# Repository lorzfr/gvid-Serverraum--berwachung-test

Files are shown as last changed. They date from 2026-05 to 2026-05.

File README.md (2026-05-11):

# Serverraumüberwachung mit automatischer Lüftersteuerung

Arduino-Projekt zur Überwachung eines Serverraums: Temperaturmessung, automatische PWM-Lüftersteuerung, Abstandserkennung als Lüfter-Stopp und Statusanzeige auf einem 16x2-I2C-LCD.

Es gibt zwei Sketch-Varianten:

| Sketch | Sensoren | Zusatznutzen |
|---|---|---|
| `serverroom_fan_control-TMP36.ino` | TMP36 + HC-SR04 | schnelle analoge Temperaturmessung |
| `serverroom_fan_control_dht11.ino` | DHT11 + HC-SR04 | Temperatur plus Luftfeuchtigkeit |

## Funktionen

- Temperaturabhängige Lüfterfreigabe mit Hysterese:
  - Einschalten ab `30.0 °C`
  - Ausschalten unter `28.0 °C`
- PWM-Regelung zwischen `FAN_PWM_MIN = 100` und `FAN_PWM_MAX = 255`
- Glättung der Temperaturwerte per gleitendem Mittelwert
  - TMP36: 10 Messwerte
  - DHT11: 5 Messwerte
- Personenerkennung über HC-SR04:
  - unter `50 cm` wird der Lüfter abgeschaltet
- Failsafe bei Sensorfehlern:
  - TMP36-Version: HC-SR04-Fehler setzt den Lüfter auf 100 %
  - DHT11-Version: DHT11- oder HC-SR04-Fehler setzt den Lüfter auf 100 %
- Serielle Debug-Ausgabe mit `9600 Baud`

## Hardware

- Arduino Mega 2560
- 5-V-Lüfter mit PWM-/Steuereingang oder geeigneter Treiberstufe
- TMP36 **oder** DHT11
- HC-SR04 Ultraschallsensor
- 16x2-I2C-LCD, Standardadresse im Code: `0x27`
- Jumper-Kabel, ggf. Breadboard

> Wichtig: Einen Lüfter nicht direkt über einen Arduino-I/O-Pin mit Strom versorgen. Der Pin `D9` ist in den Sketches als PWM-/Steuersignal vorgesehen. Die Lüfterversorgung muss zur Stromaufnahme des Lüfters passen; bei einem einfachen DC-Lüfter wird eine Treiberstufe, z. B. Transistor oder MOSFET mit Freilaufdiode, benötigt.

## Pinbelegung

### Gemeinsame Anschlüsse

| Komponente | Anschluss | Arduino Mega 2560 |
|---|---:|---:|
| HC-SR04 | TRIG | D3 |
| HC-SR04 | ECHO | D4 |
| HC-SR04 | VCC | 5V |
| HC-SR04 | GND | GND |
| Lüfter | PWM/Steuersignal | D9 |
| I2C-LCD | SDA | D20/SDA |
| I2C-LCD | SCL | D21/SCL |
| I2C-LCD | VCC | 5V |
| I2C-LCD | GND | GND |

### TMP36-Version

| Komponente | Anschluss | Arduino Mega 2560 |
|---|---:|---:|
| TMP36 | Signal | A0 |
| TMP36 | VCC | 5V |
| TMP36 | GND | GND |

### DHT11-Version

| Komponente | Anschluss | Arduino Mega 2560 |
|---|---:|---:|
| DHT11 | DAT | D2 |
| DHT11 | VCC | 5V |
| DHT11 | GND | GND |

> Hinweis: Bei einem nackten DHT11-Sensor wird normalerweise ein Pull-up-Widerstand zwischen DAT und VCC benötigt. Viele DHT11-Module haben diesen Widerstand bereits auf der Platine.

## Benötigte Arduino-Libraries

Über den Arduino Library Manager installieren:

- Für beide Sketches: `LiquidCrystal_I2C` von Frank de Brabander
- Zusätzlich für `serverroom_fan_control_dht11.ino`:
  - `DHT sensor library` von Adafruit
  - `Adafruit Unified Sensor` von Adafruit

## Schnellstart

1. Hardware nach Pinbelegung anschließen.
2. Gewünschte Sketch-Variante in der Arduino IDE öffnen:
   - `serverroom_fan_control-TMP36.ino`
   - oder `serverroom_fan_control_dht11.ino`
3. Benötigte Libraries installieren.
4. Board `Arduino Mega or Mega 2560` und den richtigen Port auswählen.
5. Sketch hochladen.
6. Seriellen Monitor auf `9600 Baud` öffnen oder Werte auf dem LCD prüfen.
7. Wenn das LCD leer bleibt, im Sketch `LCD_I2C_ADDR` von `0x27` auf `0x3F` ändern und erneut hochladen.

## Funktionstest

- Sensor erwärmen: Lüfterfreigabe startet ab etwa `30 °C`.
- Sensor abkühlen lassen: Lüfterfreigabe endet erst unter `28 °C`.
- Hand vor den HC-SR04 halten: Bei weniger als `50 cm` wird `PERSON DETECTED!` angezeigt und der Lüfter stoppt.
- HC-SR04-Echo-Verbindung trennen oder Timeout simulieren: Failsafe setzt den Lüfter auf 100 %.
- Nur DHT11-Version: DHT11 trennen oder Fehlmessung auslösen; das Display zeigt `ERR`/`SENSOR ERROR!`, der Lüfter läuft mit 100 %.

## Dateien im Repository

```text
.
├── README.md
├── LICENSE
├── doc/
│   ├── dokumenation.md
│   └── Dokumentation-als-PDF.txt
├── serverroom_fan_control-TMP36.ino
├── serverroom_fan_control_dht11.ino
├── serverraumüberwachung.fzz
├── serverraumüberwachung_bb.png
├── serverraumüberwachung_PAP.png
├── IMG_2060.jpeg
├── IMG_2066.jpeg
└── IMG_2067.jpeg
```

## Dokumentation und Medien

- Ausführlichere Projektdokumentation: `doc/dokumenation.md`
- Hinweis zur PDF-Abgabe: `doc/Dokumentation-als-PDF.txt`
- Fritzing-Projekt: `serverraumüberwachung.fzz`
- Exportierter Breadboard-Aufbau: `serverraumüberwachung_bb.png`
- Programmablaufplan: `serverraumüberwachung_PAP.png`
- Fotos des Aufbaus: `IMG_2060.jpeg`, `IMG_2066.jpeg`, `IMG_2067.jpeg`

## Bilder

### Fritzing-Aufbau

Fritzing-Export des Breadboard-Aufbaus

### Programmablaufplan

Programmablaufplan

### Realer Aufbau

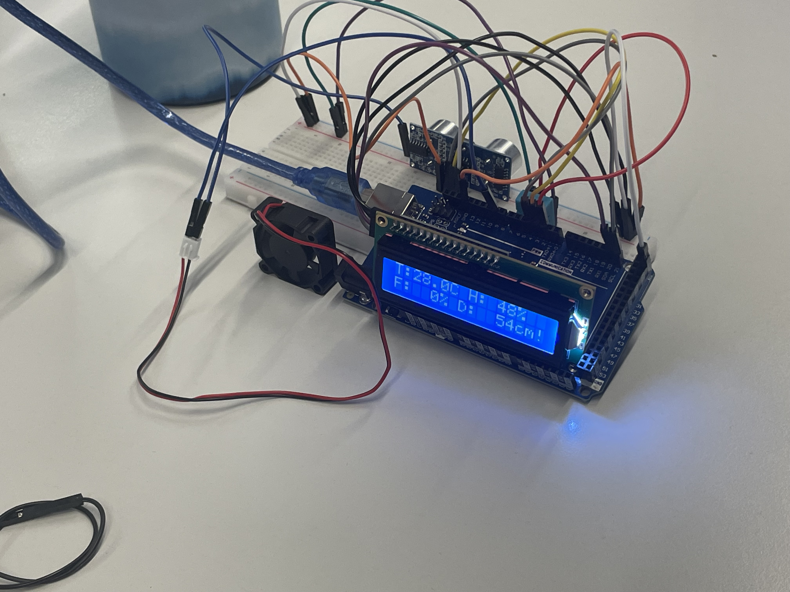
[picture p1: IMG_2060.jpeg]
Aufbau 1

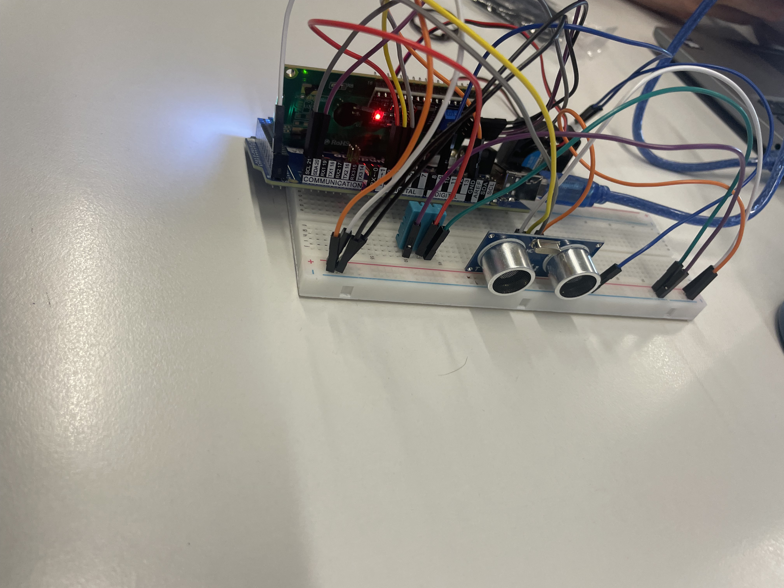
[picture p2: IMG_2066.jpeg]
Aufbau 2

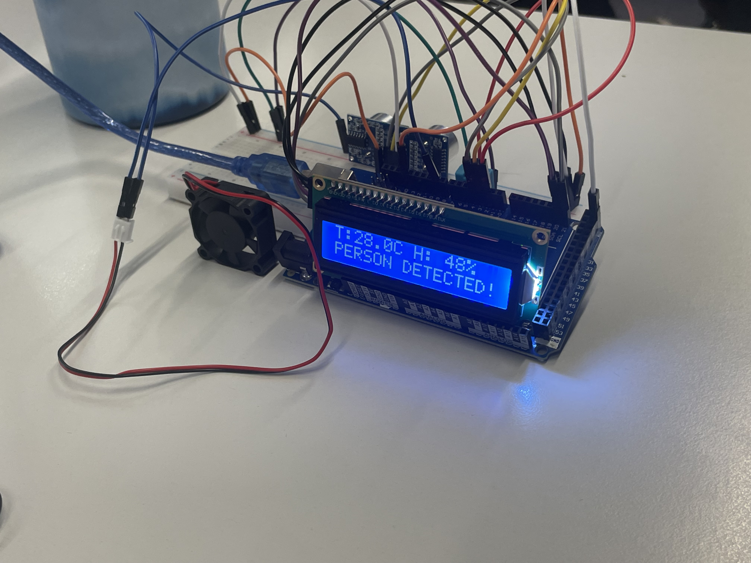
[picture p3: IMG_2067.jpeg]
Aufbau 3


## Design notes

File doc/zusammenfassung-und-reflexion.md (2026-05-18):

# 5. Zusammenfassung und Reflexion

Dieses Kapitel fasst den aktuellen Stand der Serverraumüberwachung zusammen, bewertet die erreichten Ergebnisse und beschreibt sinnvolle Erweiterungen für eine mögliche Version 2.0. Im Mittelpunkt stehen die temperaturabhängige Lüftersteuerung, die Sicherheitsabschaltung über Abstandserkennung, die Anzeige der Betriebswerte und der Umgang mit Sensorfehlern.

## 5.1 Ergebnisse: Was funktioniert gut?

Das Projekt erfüllt die wichtigsten Anforderungen an eine einfache Serverraumüberwachung. Die Temperatur wird regelmäßig erfasst und als Grundlage für die automatische Lüftersteuerung genutzt. Dadurch muss der Lüfter nicht dauerhaft mit voller Leistung laufen, sondern wird abhängig von der gemessenen Temperatur geregelt. Das spart Energie, reduziert Geräusche und sorgt trotzdem dafür, dass bei steigender Temperatur aktiv gekühlt wird.

Besonders gut funktioniert die Hysterese zwischen Einschalt- und Ausschaltpunkt. Der Lüfter startet erst ab einer definierten Temperatur und schaltet erst wieder ab, wenn die Temperatur ausreichend gefallen ist. Dadurch wird verhindert, dass der Lüfter bei kleinen Messschwankungen ständig an- und ausgeht. Diese Logik macht das System stabiler und praxistauglicher.

Auch die PWM-Regelung ist ein wichtiger Vorteil. Der Lüfter wird nicht nur ein- oder ausgeschaltet, sondern kann in seiner Leistung angepasst werden. Mit einem Mindest-PWM-Wert wird sichergestellt, dass der Lüfter zuverlässig anlaufen kann, sobald Kühlung benötigt wird. Bei höheren Temperaturen wird die Lüfterleistung weiter erhöht.

Die Glättung der Temperaturwerte verbessert die Anzeige und die Regelung. Einzelne Ausreißer oder kleine Messungenauigkeiten wirken sich dadurch weniger stark auf das Verhalten des Lüfters aus. Das ist vor allem bei analogen Sensoren wie dem TMP36 hilfreich, aber auch bei digitalen Messwerten sinnvoll.

Die Personenerkennung über den HC-SR04 ist ebenfalls ein sinnvoller Sicherheitsbestandteil. Wenn eine Person oder ein Gegenstand zu nah am Lüfter erkannt wird, stoppt der Lüfter automatisch. Damit wird das Projekt nicht nur als Temperaturregelung, sondern auch als sicherheitsbewusstes Überwachungssystem umgesetzt.

Ein weiterer positiver Punkt ist die Fehlerbehandlung. Bei ungültigen Sensorwerten oder Problemen mit der Abstandsmessung wird ein Failsafe aktiviert. Der Lüfter läuft dann mit voller Leistung, damit im Zweifel eher gekühlt wird, anstatt eine mögliche Überhitzung zu riskieren. Besonders in einem Serverraum ist dieses Verhalten sinnvoll, weil ein Ausfall der Kühlung größere Schäden verursachen könnte.

Die Ausgabe auf dem LCD und über den seriellen Monitor erleichtert die Kontrolle des Systems. Temperatur, Lüfterleistung, Abstand und Statusmeldungen können direkt beobachtet werden. Dadurch lassen sich Tests einfacher durchführen und Fehler schneller eingrenzen.

Zusammengefasst funktionieren vor allem diese Punkte gut:

- automatische Temperaturüberwachung,
- temperaturabhängige Lüftersteuerung mit PWM,
- stabile Hysterese gegen häufiges Ein- und Ausschalten,
- geglättete Messwerte für ruhigere Regelung,
- Personenerkennung als Sicherheitsfunktion,
- Failsafe bei Sensorfehlern,
- verständliche Anzeige von Messwerten und Statusinformationen.

## 5.2 Probleme: Wo gibt es noch offene Baustellen?

Trotz der funktionierenden Grundfunktionen gibt es noch einige offene Punkte. Die Genauigkeit der Temperaturmessung hängt stark vom verwendeten Sensor und von der Positionierung im Aufbau ab. Ein TMP36 kann durch analoge Störungen beeinflusst werden, während ein DHT11 vergleichsweise langsam und ungenau ist. Für eine echte Serverraumüberwachung wäre eine genauere und professionellere Sensorik sinnvoll.

Auch die Luftfeuchtigkeit wird nur in der DHT11-Version erfasst. In einem Serverraum ist Luftfeuchtigkeit jedoch ebenfalls relevant, weil zu hohe oder zu niedrige Werte langfristig problematisch für elektronische Geräte sein können. In der aktuellen Umsetzung wird die Luftfeuchtigkeit zwar angezeigt, aber noch nicht aktiv für Warnungen oder Regelentscheidungen genutzt.

Die Abstandsmessung mit dem HC-SR04 kann in bestimmten Situationen unzuverlässig sein. Schräg stehende Flächen, weiche Materialien oder ungünstige Reflexionen können Messfehler verursachen. Außerdem ist die Personenerkennung sehr einfach umgesetzt: Alles unterhalb des Grenzwerts wird als Person oder Hindernis interpretiert. Eine genauere Unterscheidung findet noch nicht statt.

Eine weitere Baustelle ist die Hardware-Auslegung des Lüfters. Der Arduino-Pin darf den Lüfter nicht direkt mit Strom versorgen. Für einen dauerhaft zuverlässigen Betrieb ist eine passende Treiberstufe mit Transistor oder MOSFET sowie eine sichere Spannungsversorgung notwendig. Dieser Punkt ist wichtig, wenn aus dem Versuchsaufbau ein dauerhaft nutzbares System werden soll.

Die Anzeige ist nützlich, aber durch das 16x2-LCD begrenzt. Es können nur wenige Informationen gleichzeitig dargestellt werden. Für ausführlichere Diagnosen, Verlaufsdaten oder mehrere Sensorwerte wäre eine umfangreichere Benutzeroberfläche besser geeignet.

Außerdem speichert das System aktuell keine Messwerte. Nach einem Neustart oder nach einem Fehler ist nicht nachvollziehbar, wie sich Temperatur, Abstand oder Fehlerzustände vorher entwickelt haben. Für eine echte Überwachung wäre Logging sehr hilfreich.

Offene Baustellen sind daher vor allem:

- begrenzte Genauigkeit der verwendeten Sensoren,
- keine Kalibrierung der Temperaturmessung,
- Luftfeuchtigkeit wird noch nicht für Alarme genutzt,
- mögliche Fehlmessungen beim Ultraschallsensor,
- einfache Hindernis-/Personenerkennung ohne Plausibilitätsprüfung,
- notwendige robuste Lüfter-Treiberstufe für den Dauerbetrieb,
- begrenzte Informationsdarstellung auf dem LCD,
- keine Speicherung oder Auswertung von Messdaten.

## 5.3 Ausblick: Welche Funktionen könnten in einer Version 2.0 ergänzt werden?

In einer Version 2.0 könnte das Projekt deutlich erweitert und näher an eine professionelle Serverraumüberwachung gebracht werden. Eine wichtige Verbesserung wäre der Einsatz genauerer Sensoren, zum Beispiel eines DHT22, BME280 oder eines anderen präziseren Temperatur- und Feuchtigkeitssensors. Damit könnten Temperatur und Luftfeuchtigkeit zuverlässiger gemessen und besser ausgewertet werden.

Zusätzlich wäre ein Datenlogging sinnvoll. Messwerte könnten auf einer SD-Karte gespeichert oder über eine Netzwerkverbindung an einen Server gesendet werden. Dadurch ließen sich Temperaturverläufe analysieren, Fehlerereignisse dokumentieren und Langzeittests besser auswerten.

Eine Alarmfunktion wäre ebenfalls ein großer Mehrwert. Bei zu hoher Temperatur, kritischer Luftfeuchtigkeit oder Sensorfehlern könnte das System über eine LED, einen Buzzer, eine E-Mail, eine Push-Nachricht oder eine Web-Oberfläche warnen. Dadurch müsste nicht dauerhaft jemand das LCD beobachten.

Für eine moderne Umsetzung könnte ein ESP32 oder ein ähnlicher Mikrocontroller genutzt werden. Damit wäre eine WLAN-Anbindung möglich. Das System könnte dann ein Web-Dashboard bereitstellen, Messwerte live anzeigen und Einstellungen wie Grenzwerte oder Betriebsmodi direkt über den Browser anpassbar machen.

Auch mehrere Sensoren wären sinnvoll. In einem Serverraum gibt es oft Temperaturunterschiede zwischen verschiedenen Bereichen. Mit mehreren Messpunkten könnte das System Hotspots erkennen und die Lüftersteuerung genauer anpassen.

Für den praktischen Betrieb wären außerdem verschiedene Betriebsmodi hilfreich. Neben dem Automatikmodus könnte es einen manuellen Modus, einen Wartungsmodus und einen Notfallmodus geben. So könnte der Lüfter bei Tests gezielt gesteuert oder bei Wartungsarbeiten sicher deaktiviert werden.

Mögliche Erweiterungen für Version 2.0 sind:

- präzisere Sensoren wie DHT22 oder BME280,
- Kalibrierfunktion für Temperatur- und Feuchtigkeitswerte,
- Speicherung von Messwerten auf SD-Karte,
- Netzwerkübertragung der Daten,
- Web-Dashboard für Live-Anzeige und Konfiguration,
- Alarmierung per LED, Buzzer, E-Mail oder Push-Nachricht,
- mehrere Temperaturmesspunkte im Raum,
- Grenzwerte für Luftfeuchtigkeit,
- bessere Plausibilitätsprüfung der Abstandsmessung,
- einstellbare Betriebsmodi wie Auto, Manuell, Wartung und Notfall,
- stabilere Hardware mit geeigneter Lüfter-Treiberstufe und Gehäuse.

Insgesamt bietet die aktuelle Version eine funktionierende Grundlage. Die wichtigsten Kernfunktionen sind vorhanden, aber Version 2.0 könnte das System genauer, komfortabler, besser vernetzbar und zuverlässiger für den Dauerbetrieb machen.

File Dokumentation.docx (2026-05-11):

Serverraum Überwachungssystem

- Was wurde entwickelt und warum?

Wir haben ein Überwachungssystem entwickelt um unseren Serverraum rund um die Uhr Sicher und ihm eine geeignete Umgebung zu gewährleisten. Darunter zählen ein Temperatur Messer, einen Abstandsmesser und einen Feuchtigkeitsmesser.

- Ziele und Anforderungen

Unser Überwachungssystem soll dafür sorgen, dass der Serverraum nie zu warm oder zu feucht wird. Außerdem sollen bei Arbeiten im Serverraum der Lüfter für die Kühlung ausgeschaltet werden, um das Unfallrisiko zu verringern.

- Verwendete Technologien
- Hardware: Arduino, Bread-Board, Ultraschallsensor, LCD-Bildschirm, 12V Lüfter, Kabel, USB-A auf USB-B Kabel
- Software: fritzing
- Teammitglieder
- Um die Software hat Lars sich gekümmert und das Skript geschrieben
- Hardwareinstallation hat Luca übernommen
- Dokumentation haben beide zusammen bearbeitet

18.05.2026 Herr Meier

Inhaltsverzeichnis

1. Technische Dokumentation
  - Schaltplan
  - Hardwareliste
2. Code-Dokumentation
  - Logik-Visualisierung
  - Quellcode
3. Testphase und Fehlerbehebung
  - Fehlerprotokoll
  - Testreihen
4. Benutzeranleitung
  - Wie wird das System gestartet?
  - Welche Bedienelemente (Taster, Potentiometer) gibt es?
  - Wie interpretiert man die Ausgaben auf dem Display
5. Zusammenfassung und Reflektion
  - Ergebnisse: Was funktioniert gut?
  - Probleme: Wo gibt es noch offene Baustellen?
  - Ausblick: Welche Funktionen könnten in einer Version 2.0 ergänzt werden

Technische Dokumentation

- Der Schaltplan

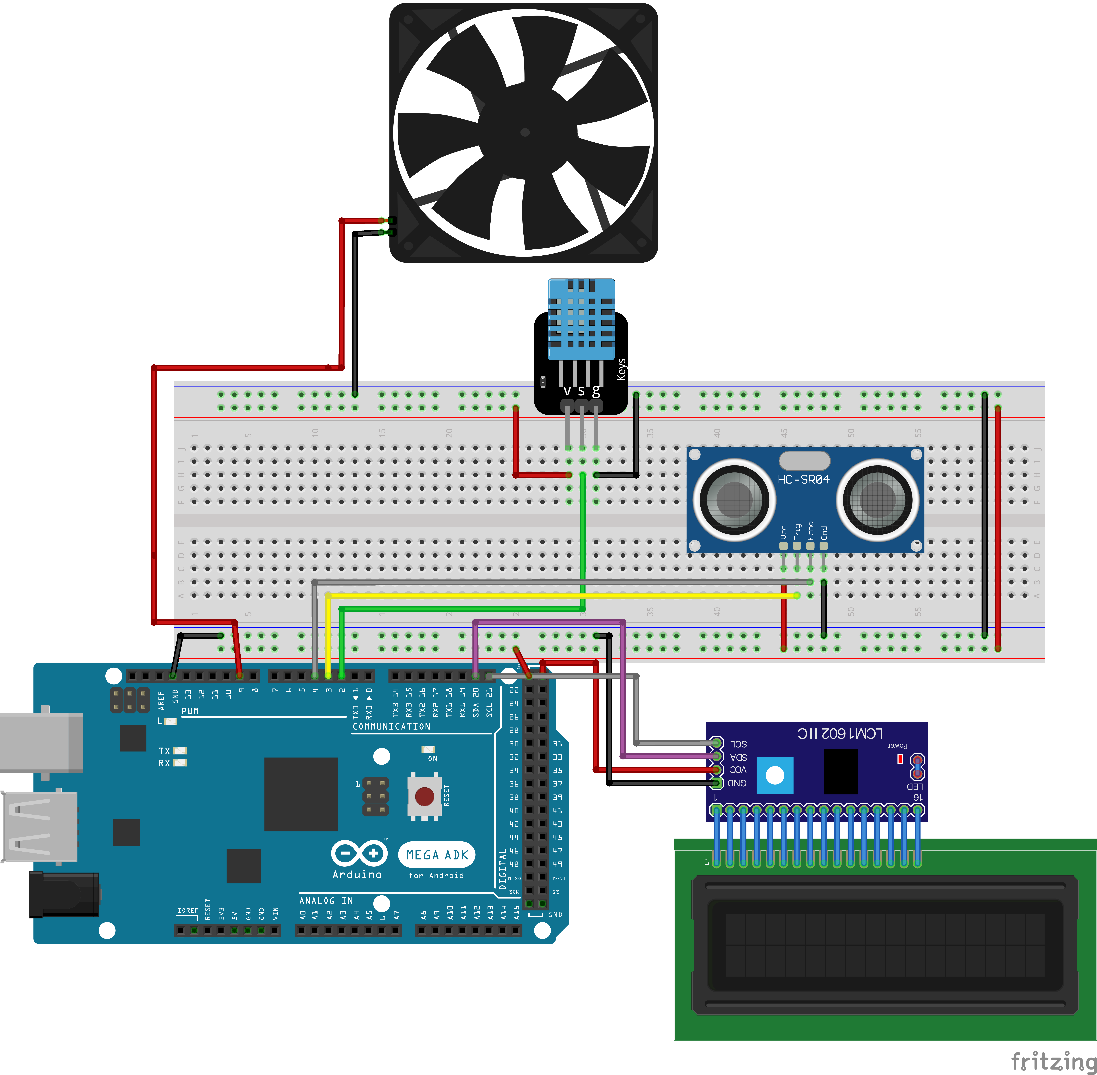
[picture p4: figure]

Hardwareliste

1x Arduino Mega 2560

1x TMP36 oder 1x DHT11

1x HC-SR04 Ultraschallsensor

1x I2C LCD 16x2

1x 5V PWM-Lüfter

Verbindungskabel, ggf. Breadboard

Code-Dokumentation

- Logik-Visualisierung

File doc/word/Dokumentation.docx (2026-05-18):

Serverraum Überwachungssystem

- Was wurde entwickelt und warum?

Wir haben ein Überwachungssystem entwickelt um unseren Serverraum rund um die Uhr Sicher und ihm eine geeignete Umgebung zu gewährleisten. Darunter zählen ein Temperatur Messer, einen Abstandsmesser und einen Feuchtigkeitsmesser.

- Ziele und Anforderungen

Unser Überwachungssystem soll dafür sorgen, dass der Serverraum nie zu warm oder zu feucht wird. Außerdem sollen bei Arbeiten im Serverraum der Lüfter für die Kühlung ausgeschaltet werden, um das Unfallrisiko zu verringern.

- Verwendete Technologien
- Hardware: Arduino, Bread-Board, Ultraschallsensor, LCD-Bildschirm, 12V Lüfter, Kabel, USB-A auf USB-B Kabel
- Software: fritzing
- Teammitglieder
- Um die Software hat Lars sich gekümmert und das Skript geschrieben
- Hardwareinstallation hat Luca übernommen
- Dokumentation haben beide zusammen bearbeitet

Inhaltsverzeichnis

1. Technische Dokumentation
  1.1 Schaltplan
  1.2 Hardwareliste
2. Code-Dokumentation
  2.1 Logik-Visualisierung
  2.2 Quellcode
3. Testphase und Fehlerbehebung
  3.1 Fehlerprotokoll
  3.2 Testreihen
4. Benutzeranleitung
  4.1 Wie wird das System gestartet?
  4.2 Welche Bedienelemente (Taster, Potentiometer) gibt es?
  4.3 Wie interpretiert man die Ausgaben auf dem Display
5. Zusammenfassung und Reflektion
  5.1 Ergebnisse: Was funktioniert gut?
  5.2 Probleme: Wo gibt es noch offene Baustellen?
  5.3 Ausblick: Welche Funktionen könnten in einer Version 2.0 ergänzt werden
6. Anhang
  6.1 Anhang zum Quellcode

1. Technische Dokumentation

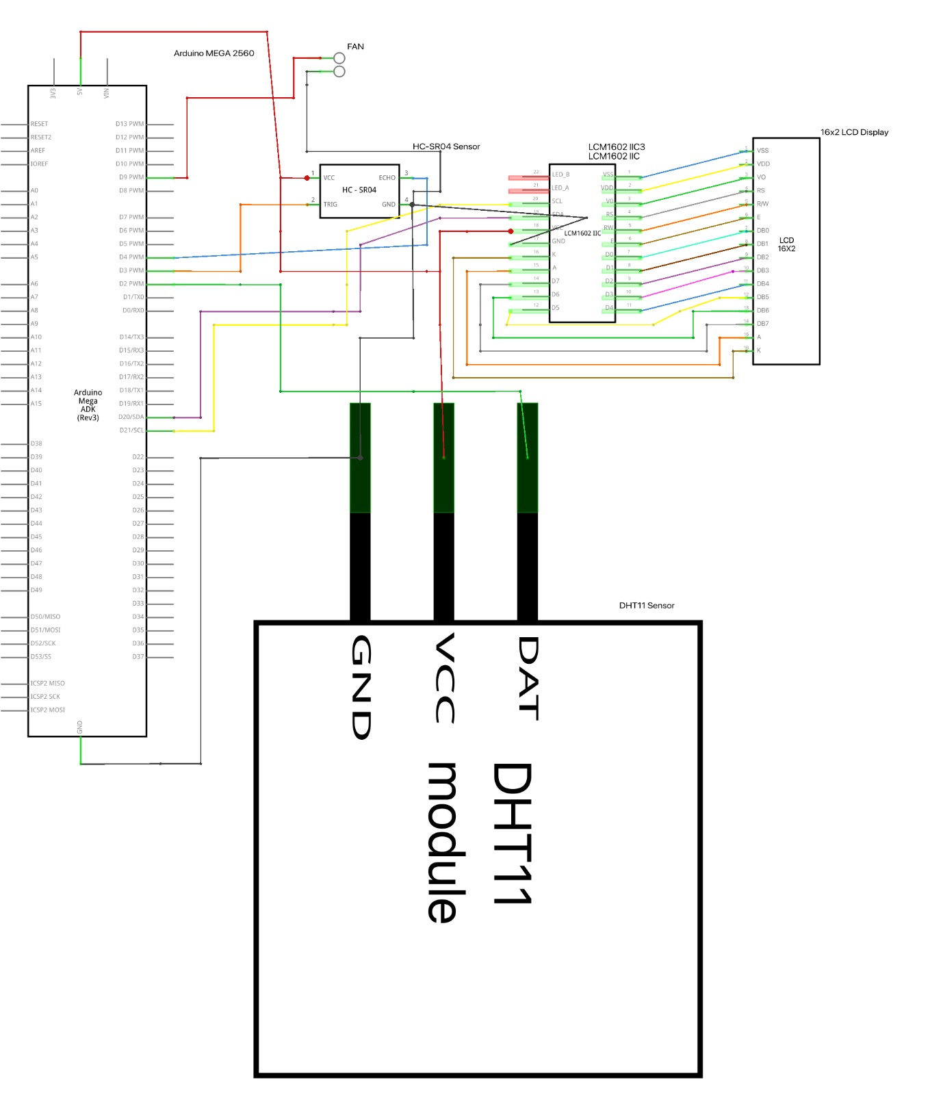
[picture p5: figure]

1.1 Der Schaltplan

1.2 Hardwareliste

1x Arduino Mega 2560

1x TMP36 oder 1x DHT11

1x HC-SR04 Ultraschallsensor

1x I2C LCD 16x2

1x 5V PWM-Lüfter

Verbindungskabel, ggf. Breadboard

2. Code-Dokumentation

2.1 Logik-Visualisierung

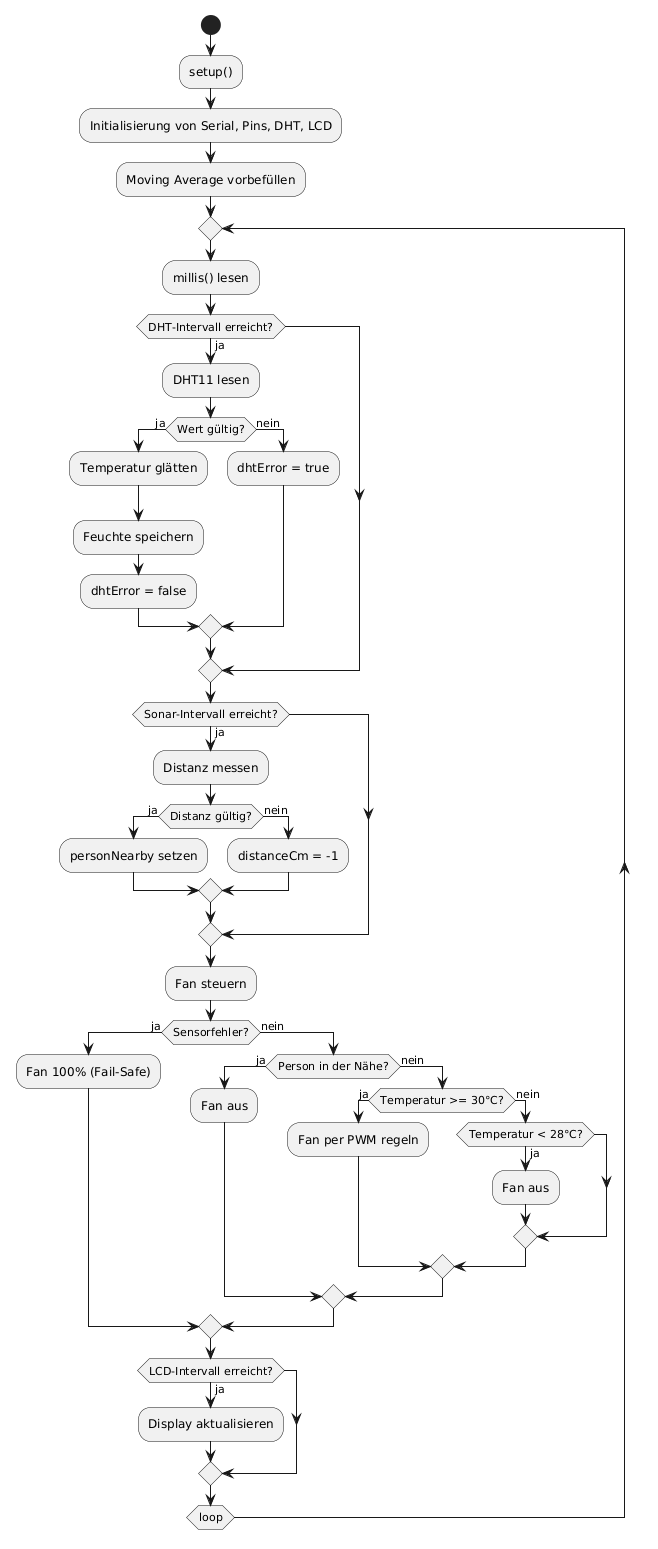
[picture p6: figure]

2. Code-Dokumentation

2.2 Der Quellcode

- Temperaturgrenzen:
  - TEMP_FAN_ON = 30.0°C
  - TEMP_FAN_OFF = 28.0°C (Hysterese)
- PWM-Mapping: linear von TEMP_MIN_MAP = 20.0°C bis TEMP_MAX_MAP = 40.0°C auf den Bereich FAN_PWM_MIN bis 255.
- Personenschutz: Wenn Distanz < PERSON_DIST_CM (50 cm), wird der Lüfter abgeschaltet.
- Failsafe: Bei Sensorausfall läuft Lüfter mit 100%, um Überhitzung zu vermeiden.
- DHT11 darf nur langsam gelesen werden, deshalb INTERVAL_DHT = 2000 ms.
- Gleitender Mittelwert mit 5 Samples (passend zur langsameren DHT11-Rate).
- Zusätzlicher Fehlerzustand dhtError; Failsafe bei DHT- oder Sonarfehler.

Wichtige Funktionen

- smoothedTemperature() – Mittelwertbildung.
- updateFan() – Failsafe bei dhtError || distanceCm == -1.
- updateDisplay() – zeigt Temperatur, Feuchte, Lüfter und Distanz; im Fehlerfall „ERR“.

3. Testphase und Fehlerbehebung

3.1 Fehlerprotokoll

1. LCD bleibt leer
  - Ursache: falsche I2C-Adresse.
  - Lösung: 0x27 auf 0x3F ändern.
2. DHT11 liefert NaN
  - Ursache: zu schnelle Abfrage / Leitungsproblem.
  - Lösung: 2-Sekunden-Intervall einhalten, Verkabelung prüfen.
3. HC-SR04 keine Werte
  - Ursache: Echo-Timeout oder Reichweite überschritten.
  - Lösung: Timeout/Verkabelung prüfen; System setzt automatisch Failsafe.
4. Lüfter startet nicht zuverlässig
  - Ursache: PWM-Startwert zu niedrig.
  - Lösung: FAN_PWM_MIN erhöhen.

3.2 Testreihen

- Schwellwerttest: Sensor erwärmen (z. B. Föhn), prüfen, ob Lüfter ab ~30°C startet.
- Hysterese-Test: Temperatur langsam senken, prüfen, ob Lüfter erst unter 28°C ausgeht.
- Personenschutz-Test: Hand vor HC-SR04 (<50 cm), Lüfter muss stoppen.
- Failsafe-Test Sonar: Echo-Leitung lösen/simulieren, Lüfter muss 100% laufen.
- Failsafe-Test DHT11: DHT11 trennen, Lüfter muss 100% laufen.
- Langzeittest: 30–60 Minuten Betrieb, stabile Anzeige und keine Hänger.
  4. Benutzeranleitung

4.1 Wie wird das System gestartet?

1. Hardware gemäß Schaltplan anschließen.
2. Passenden Sketch hochladen:
  - serverroom_fan_control-TMP36.ino oder
  - serverroom_fan_control_dht11.ino
3. Arduino mit Strom versorgen.
4. Nach Initialisierung erscheinen Messwerte auf dem LCD.

4.2 Welche Bedienelemente (Taster, Potenziometer) gibt es?

- Es gibt keine aktiven Bedienelemente; das System arbeitet automatisch.
- Optional können Grenzwerte im Code angepasst werden:
  - TEMP_FAN_ON, TEMP_FAN_OFF
  - PERSON_DIST_CM
  - FAN_PWM_MIN

4.3 Wie interpretiert man die Ausgabe auf dem Display?

- Zeile 1: Temperatur (und bei DHT11 auch Luftfeuchte)
- Zeile 2: Lüfterleistung in % und Distanz
- Sonderanzeigen:
  - PERSON DETECTED! → Lüfter aus
  - SENSOR ERROR! bzw. ERR-Werte → Failsafe aktiv
5. Zusammenfassung und Reflektion

5.1 Ergebnisse: Was funktioniert gut?

- Das System erfüllt die Kernfunktion: temperaturabhängige Lüftersteuerung.
- Sicherheits- und Failsafe-Mechanismen erhöhen die Betriebssicherheit.
- Die modulare Struktur (Lesen, Regeln, Anzeigen) verbessert Wartbarkeit und Erweiterbarkeit.

5.2 Probleme: Wo gibt es noch offene Baustellen?

- Ohne Kalibrierung können absolute Temperaturwerte je nach Sensor leicht abweichen.
- DHT11 ist relativ ungenau und langsam.
- HC-SR04 kann in engen/geometrisch ungünstigen Umgebungen Fehlmessungen erzeugen.

5.3 Ausblick: Welche Funktionen könnten in einer Version 2.0 ergänzt werden?

- Austausch DHT11 gegen DHT22 oder BME280 für genauere Messungen.
- Logging auf SD-Karte (Temperaturverlauf, Fehlerereignisse).
- Alarmfunktion (Buzzer/LED/Nachricht) bei Grenzwertüberschreitung.
- Web-Dashboard (z. B. per ESP32) für Fernüberwachung.
- Manuelle Betriebsmodi (Auto/Manuell/Service).
6. Anhang

6.1 Der Verwendete Quellcode: gvid-serverraum-ueberwachung/serverroom_fan_control_dht11.ino at main · lorzfr/gvid-serverraum-ueberwachung (https://github.com/lorzfr/gvid-serverraum-ueberwachung/blob/main/serverroom_fan_control_dht11.ino)

Lars, Luca GviD Herr Meier

18.05.2026, Löhne Dokumentation.docx

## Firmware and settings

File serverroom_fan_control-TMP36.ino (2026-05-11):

// =============================================================
//  Server Room Fan Controller – Variante mit TMP36
//
//  Ziel des Sketches:
//    * Temperatur analog über einen TMP36 messen.
//    * Per Ultraschallsensor erkennen, ob eine Person nahe am Lüfter steht.
//    * Den 5-V-Lüfter temperaturabhängig per PWM regeln.
//    * Messwerte und Status auf einem 16x2-I2C-LCD sowie seriell ausgeben.
//
//  Board  : Arduino Mega 2560
//  Sensor : TMP36  (analoger Temperatursensor)
//  Sensor : HC-SR04 (digitale Abstandsmessung)
//  Display: I2C LCD  – LED 8050 R7  (Adresse 0x27, bei Bedarf ändern)
//  Fan    : 5 V PWM-Lüfter
// =============================================================
//  Required libraries (install via Library Manager):
//    • LiquidCrystal_I2C  by Frank de Brabander
// =============================================================

#include <Wire.h>
#include <LiquidCrystal_I2C.h>

// ─── PIN CONFIGURATION ────────────────────────────────────────
// Alle Hardware-Anschlüsse werden zentral definiert, damit die
// Verkabelung später ohne Suche im Programm angepasst werden kann.
#define PIN_TMP36      A0   // Analoger TMP36-Ausgang; analogRead() liefert 0..1023.
#define PIN_TRIG        3   // HC-SR04-Trigger: Arduino sendet hier den Ultraschall-Impuls.
#define PIN_ECHO        4   // HC-SR04-Echo: Pulsdauer entspricht der gemessenen Entfernung.
#define PIN_FAN         9   // PWM-fähiger Ausgang zur Drehzahlsteuerung des Lüfters.

// ─── LCD CONFIGURATION ────────────────────────────────────────
// Adresse und Geometrie des I2C-LCDs. Bleibt das Display leer, ist
// häufig 0x3F statt 0x27 die richtige I2C-Adresse.
#define LCD_I2C_ADDR   0x27
#define LCD_COLS        16
#define LCD_ROWS         2

// ─── TEMPERATURE THRESHOLDS (°C) ──────────────────────────────
// Die Ein- und Ausschaltpunkte sind absichtlich verschieden. Diese
// Hysterese verhindert, dass der Lüfter bei ca. 30 °C ständig taktet.
#define TEMP_FAN_ON     30.0   // Ab dieser Temperatur wird die Lüfterfreigabe gesetzt.
#define TEMP_FAN_OFF    28.0   // Unter diesem Wert wird die Lüfterfreigabe wieder gelöscht.
#define TEMP_MIN_MAP    20.0   // Temperatur, die auf FAN_PWM_MIN abgebildet wird.
#define TEMP_MAX_MAP    40.0   // Temperatur, die auf FAN_PWM_MAX/255 abgebildet wird.

// ─── FAN PWM LIMITS ───────────────────────────────────────────
// PWM-Werte liegen bei Arduino analogWrite() zwischen 0 und 255.
// Viele Lüfter laufen bei sehr kleinen PWM-Werten nicht zuverlässig an.
#define FAN_PWM_MIN    100     // Mindestwert, sobald der Lüfter eingeschaltet ist.
#define FAN_PWM_MAX    255     // Maximalwert: entspricht 100 % Einschaltdauer.

// ─── PERSON DETECTION ─────────────────────────────────────────
// Der Ultraschallsensor dient als Sicherheits-/Komfortabschaltung:
// steht jemand sehr nah am Gerät, wird der Lüfter unabhängig von der
// Temperatur ausgeschaltet. Ungültige Messungen lösen den Failsafe aus.
#define PERSON_DIST_CM  50     // Unterhalb dieser Entfernung gilt: Person erkannt.
#define SONAR_MAX_CM   500     // Größere Werte werden als ungültig verworfen.
#define SONAR_TIMEOUT_US 40000UL  // Maximale Wartezeit auf Echo; 0 bedeutet Timeout.

// ─── TIMING INTERVALS (ms) ────────────────────────────────────
// Die Hauptschleife arbeitet mit millis()-Zeitstempeln statt langen
// delay()-Pausen. So bleibt die Lüfterregelung reaktionsfähig.
#define INTERVAL_TEMP   500    // Analogtemperatur regelmäßig, aber nicht unnötig oft lesen.
#define INTERVAL_SONAR  200    // Abstandsmessung wird deutlich häufiger aktualisiert.
#define INTERVAL_LCD   1000    // LCD-Refresh: langsam genug, um Flackern zu vermeiden.

// ─── MOVING AVERAGE ───────────────────────────────────────────
// Der TMP36 ist analog und kann etwas rauschen. Zehn Samples ergeben
// eine ruhige Anzeige, ohne die Regelung zu stark zu verzögern.
#define AVG_SAMPLES     10

// =============================================================
//  DATA STRUCTURES
// =============================================================

struct SensorData {
  float   tempC;          // Geglättete Temperatur in °C; Grundlage für die PWM-Regelung.
  int     distanceCm;     // Letzte Entfernung in cm; -1 kennzeichnet Timeout/Fehler.
  bool    personNearby;   // true, wenn distanceCm innerhalb PERSON_DIST_CM liegt.
};

struct FanState {
  bool  running;          // Logischer Laufzustand: true = Lüfter soll drehen.
  int   pwmValue;         // Tatsächlich ausgegebener PWM-Wert von 0 bis 255.
  int   percentSpeed;     // PWM-Wert als Prozentangabe für Display/Debug-Ausgabe.
};

SensorData sensor = { 25.0, 200, false };
FanState   fan    = { false, 0, 0 };

// ─── Internal: moving average buffer ──────────────────────────
// Ringpuffer: jeder neue Temperaturwert überschreibt den ältesten Wert.
float   tempBuffer[AVG_SAMPLES];
uint8_t tempIndex     = 0;
bool    bufferFull    = false;

// ─── Internal: non-blocking timers ────────────────────────────
// Diese Zeitstempel merken, wann ein Teilbereich zuletzt ausgeführt wurde.
unsigned long lastTempMs  = 0;
unsigned long lastSonarMs = 0;
unsigned long lastLcdMs   = 0;

// ─── Internal: hysteresis state ───────────────────────────────
// Merkt, ob die Temperaturregelung aktuell freigegeben ist. Ohne diesen
// Zustand wäre keine saubere Hysterese zwischen ON und OFF möglich.
bool fanEnabledByTemp = false;

// =============================================================
//  LCD OBJECT
// =============================================================
LiquidCrystal_I2C lcd(LCD_I2C_ADDR, LCD_COLS, LCD_ROWS);

// =============================================================
//  FUNCTION DECLARATIONS
// =============================================================
float   readTemperatureC();
float   smoothedTemperature(float newReading);
int     readDistanceCm();
int     calculatePWM(float tempC);
void    updateFan(SensorData &s, FanState &f);
void    updateDisplay(const SensorData &s, const FanState &f);
void    printPadded(int val, int width);

// =============================================================
//  SETUP
// =============================================================
void setup() {
  // setup() läuft genau einmal nach Reset/Upload. Hier wird die
  // Hardware vorbereitet und es werden sinnvolle Startwerte gesetzt.
  Serial.begin(9600);
  Serial.println(F("=== Server Room Fan Controller ==="));

  // Richtung der I/O-Pins festlegen. Der Lüfter wird direkt auf 0
  // gesetzt, damit er beim Start nicht unbeabsichtigt kurz anläuft.
  pinMode(PIN_TRIG, OUTPUT);
  pinMode(PIN_ECHO, INPUT);
  pinMode(PIN_FAN,  OUTPUT);
  analogWrite(PIN_FAN, 0);

  // Mittelwertpuffer mit einem realen Startwert füllen. Dadurch zeigt
  // die erste Berechnung keinen künstlichen Durchschnitt aus Nullen.
  float firstRead = readTemperatureC();
  for (uint8_t i = 0; i < AVG_SAMPLES; i++) {
    tempBuffer[i] = firstRead;
  }
  sensor.tempC = firstRead;

  // LCD starten und eine kurze Initialisierungsmeldung anzeigen.
  lcd.init();
  lcd.backlight();
  lcd.clear();
  lcd.setCursor(0, 0);
  lcd.print(F("Server Room Fan"));
  lcd.setCursor(0, 1);
  lcd.print(F("  Initializing.."));
  delay(1500);
  lcd.clear();
}

// =============================================================
//  LOOP – zyklische, weitgehend nicht-blockierende Steuerung
// =============================================================
void loop() {
  // Aktuelle Laufzeit einmal speichern. Alle Zeitvergleiche nutzen
  // denselben Wert, dadurch bleiben die Teilaufgaben konsistent.
  unsigned long now = millis();

  // ── 1. Temperaturmessung ────────────────────────────────────
  // Nur bei abgelaufenem Intervall lesen und anschließend glätten.
  // Die analoge Messung ist schnell, das Intervall reduziert aber Rauschen.
  if (now - lastTempMs >= INTERVAL_TEMP) {
    lastTempMs = now;
    float raw    = readTemperatureC();
    sensor.tempC = smoothedTemperature(raw);
  }

  // ── 2. Ultraschall / Personenerkennung ───────────────────────
  // Eine positive Entfernung unterhalb PERSON_DIST_CM sperrt den Lüfter.
  // -1 bedeutet Messfehler/Timeout und wird später als Failsafe behandelt.
  if (now - lastSonarMs >= INTERVAL_SONAR) {
    lastSonarMs = now;
    sensor.distanceCm  = readDistanceCm();
    sensor.personNearby = (sensor.distanceCm > 0 &&
                           sensor.distanceCm < PERSON_DIST_CM);
  }

  // ── 3. Lüfterregelung ────────────────────────────────────────
  // Diese Funktion fasst Sensorfehler, Personenerkennung, Hysterese und
  // PWM-Berechnung zu einer klaren Stellgröße für den Lüfter zusammen.
  updateFan(sensor, fan);

  // ── 4. Display/Debug-Ausgabe ─────────────────────────────────
  // Das LCD muss nicht bei jedem loop()-Durchlauf aktualisiert werden.
  if (now - lastLcdMs >= INTERVAL_LCD) {
    lastLcdMs = now;
    updateDisplay(sensor, fan);
  }
}

// =============================================================
//  TEMPERATURE  –  TMP36
// =============================================================
// Der TMP36 liefert 750 mV bei 25 °C und ändert sich um 10 mV/°C.
// Formel: Temp(°C) = (mV - 500) / 10. Bei 5-V-Referenz gilt:
// mV = analogRead * (5000.0 / 1024.0).
float readTemperatureC() {
  int   raw = analogRead(PIN_TMP36);      // 10-bit ADC-Wert: 0..1023
  float mV  = raw * (5000.0 / 1024.0);   // ADC-Wert in Millivolt umrechnen.
  float tempC = (mV - 500.0) / 10.0;     // TMP36-Offset und Steigung anwenden.
  return tempC;
}

// Speichert neue Messwerte in einem Ringpuffer und bildet daraus den
// Durchschnitt. Dadurch reagiert der Lüfter nicht auf einzelne Ausreißer.
float smoothedTemperature(float newReading) {
  tempBuffer[tempIndex] = newReading;          // Neuen Wert an aktueller Position ablegen.
  tempIndex = (tempIndex + 1) % AVG_SAMPLES;   // Index zyklisch weiterschalten.
  if (tempIndex == 0) bufferFull = true;       // Nach einem Umlauf sind alle Plätze belegt.

  uint8_t count = bufferFull ? AVG_SAMPLES : tempIndex;  // Beim Start nur gefüllte Felder mitteln.
  float   sum   = 0.0;
  for (uint8_t i = 0; i < count; i++) sum += tempBuffer[i];
  return sum / count;
}

// =============================================================
//  DISTANCE  –  HC-SR04
// =============================================================
// Erzeugt den Triggerimpuls, misst die Echo-Pulsdauer und rechnet sie
// in Zentimeter um. Rückgabewert -1 bedeutet: Messung unbrauchbar.
int readDistanceCm() {
  // Sauberer Trigger: kurz LOW, dann 10 µs HIGH, danach wieder LOW.
  digitalWrite(PIN_TRIG, LOW);
  delayMicroseconds(2);
  digitalWrite(PIN_TRIG, HIGH);
  delayMicroseconds(10);
  digitalWrite(PIN_TRIG, LOW);

  // pulseIn() blockiert maximal SONAR_TIMEOUT_US. Dauer 0 = kein Echo.
  long duration = pulseIn(PIN_ECHO, HIGH, SONAR_TIMEOUT_US);

  if (duration == 0) {
    // Timeout: Sensor getrennt, Echo zu schwach oder Objekt zu weit entfernt.
    return -1;
  }

  // Faustformel HC-SR04: Mikrosekunden / 58 ≈ Entfernung in cm.
  int cm = (int)(duration / 58);
  if (cm > SONAR_MAX_CM) return -1;  // unrealistische Werte verwerfen
  return cm;
}

// =============================================================
//  FAN CONTROL
//  calculatePWM() bildet die Temperatur linear auf den zulässigen
//  PWM-Bereich ab. updateFan() entscheidet anschließend, ob dieser
//  Wert ausgegeben oder wegen Person/Fehler auf 0/100 % gesetzt wird.
// =============================================================
int calculatePWM(float tempC) {
  // map() arbeitet ganzzahlig; Skalierung x10 erhält eine Nachkommastelle.
  long pwm = map(
    (long)(tempC  * 10),
    (long)(TEMP_MIN_MAP * 10),
    (long)(TEMP_MAX_MAP * 10),
    FAN_PWM_MIN,
    FAN_PWM_MAX
  );
  return (int)constrain(pwm, FAN_PWM_MIN, FAN_PWM_MAX);
}

void updateFan(SensorData &s, FanState &f) {
  // Priorität der Regeln:
  //   1. Sensorfehler -> maximal kühlen (Schutz des Serverraums).
  //   2. Person in der Nähe -> Lüfter aus (Sicherheit/Komfort).
  //   3. Temperaturregelung mit Hysterese und PWM-Kennlinie.

  // ── Failsafe: Sonar-Timeout (-1) -> volle Drehzahl ──────────
  if (s.distanceCm == -1) {
    f.running      = true;
    f.pwmValue     = FAN_PWM_MAX;
    f.percentSpeed = 100;
    analogWrite(PIN_FAN, f.pwmValue);
    Serial.println(F("[FAILSAFE] Sonar error – fan at 100%"));
    return;
  }

  // ── Person in der Nähe -> Lüfter zwangsweise aus ────────────
  if (s.personNearby) {
    f.running      = false;
    f.pwmValue     = 0;
    f.percentSpeed = 0;
    analogWrite(PIN_FAN, 0);
    return;
  }

  // ── Hysterese für Temperaturschwelle ────────────────────────
  // Einschalten erst ab TEMP_FAN_ON, Ausschalten erst unter TEMP_FAN_OFF.
  // Dadurch bleibt der Zustand zwischen 28 °C und 30 °C stabil.
  if (!fanEnabledByTemp && s.tempC >= TEMP_FAN_ON)  fanEnabledByTemp = true;
  if ( fanEnabledByTemp && s.tempC <  TEMP_FAN_OFF) fanEnabledByTemp = false;

  if (fanEnabledByTemp) {
    f.running      = true;
    f.pwmValue     = calculatePWM(s.tempC);  // wärmer = höherer PWM-Wert
    f.percentSpeed = map(f.pwmValue, 0, FAN_PWM_MAX, 0, 100);
    analogWrite(PIN_FAN, f.pwmValue);
  } else {
    f.running      = false;
    f.pwmValue     = 0;
    f.percentSpeed = 0;
    analogWrite(PIN_FAN, 0);
  }
}

// =============================================================
//  LCD DISPLAY  –  16x2 layout
//
//  Row 0:  "T:  25.3C  F: 65%"
//  Row 1:  "Dist: 120cm  OK "   or "PERSON DETECTED!"
//           (failsafe) "SENSOR ERROR!  "
// =============================================================
void updateDisplay(const SensorData &s, const FanState &f) {
  // ── Zeile 0: Temperatur + Lüfterleistung ───────────────────
  lcd.setCursor(0, 0);
  lcd.print(F("T:"));
  // Temperatur mit einer Nachkommastelle; danach folgt die aktuelle Lüfterleistung.
  lcd.print(s.tempC, 1);
  lcd.print(F("C  F:"));
  printPadded(f.percentSpeed, 3);
  lcd.print(F("%"));

  // ── Zeile 1: Entfernung oder Statusmeldung ─────────────────
  // Statusmeldungen haben Vorrang vor Zahlenwerten, weil sie für den
  // Betreiber wichtiger sind als die Detailanzeige.
  lcd.setCursor(0, 1);
  if (s.distanceCm == -1) {
    lcd.print(F("SENSOR ERROR!   "));
  } else if (s.personNearby) {
    lcd.print(F("PERSON DETECTED!"));
  } else {
    lcd.print(F("Dist:"));
    printPadded(s.distanceCm, 4);
    lcd.print(F("cm      "));
  }

  // ── Serielle Debug-Ausgabe ──────────────────────────────────
  // Diese Werte helfen beim Abgleich mit realen Sensorwerten im
  // Serial Monitor bei 9600 Baud.
  Serial.print(F("Temp: "));    Serial.print(s.tempC, 1);
  Serial.print(F("°C  Fan: ")); Serial.print(f.percentSpeed);
  Serial.print(F("%  Dist: ")); Serial.print(s.distanceCm);
  Serial.print(F("cm  Person: ")); Serial.println(s.personNearby ? F("YES") : F("NO"));
}

// Gibt Zahlen rechtsbündig mit führenden Leerzeichen aus. Dadurch
// werden bei kürzeren neuen Werten alte LCD-Ziffern zuverlässig gelöscht.
void printPadded(int val, int width) {
  String s = String(val);
  for (int i = s.length(); i < width; i++) lcd.print(' ');
  lcd.print(s);
}
